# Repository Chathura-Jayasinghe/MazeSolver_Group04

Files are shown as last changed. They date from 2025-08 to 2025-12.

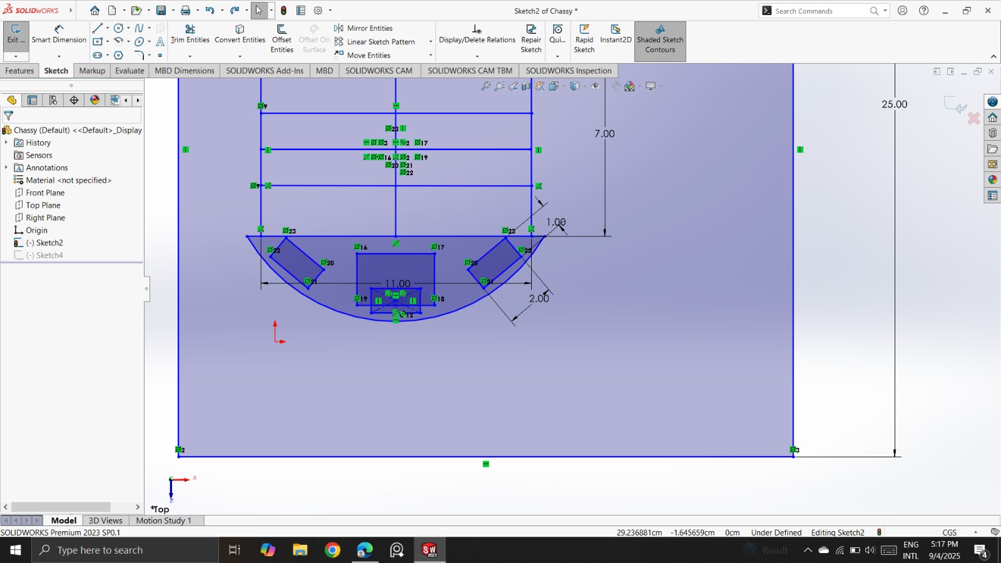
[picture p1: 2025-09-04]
images/WhatsApp Image 2025-09-04 at 17.18.16_0e4c124f.jpg

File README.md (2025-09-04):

# Maze-solving-robot

This project presents a **maze-solving robot** developed by **Group 4** as part of our coursework. The robot is designed to autonomously navigate through a maze by detecting paths, avoiding obstacles, and finding the optimal route to the destination.

The implementation focuses on:

* **Sensor integration** for line detection and obstacle avoidance.
* **Microcontroller programming** to execute decision-making algorithms.
* **Efficient pathfinding techniques** to minimize traversal time.
* **Robust mechanical design** for smooth and accurate movement.

Through this project, we aimed to enhance our knowledge of embedded systems, robotics, and algorithm design while working collaboratively as a team.

---

## Team Members – Group 4

| Member | Student ID | Name |
| --- | --- | --- |
| 1 | 210248E | J.M.C.N.B. Jayasinghe |
| 2 | 210367R | D.N. Manamperi |
| 3 | 210486F | M.R.M. Prabhashana |
| 4 | 210337C | G.N.K. Lakshitha |

---
<table>
  <tr>
    <td>
      Front View<br/>
      <p align="center"><b>Front View</b></p>
    </td>
    <td>
      Side View<br/>
      <p align="center"><b>Side View</b></p>
    </td>
    <td>
      Plan View<br/>
      <p align="center"><b>Plan View</b></p>
    </td>
  </tr>
</table>

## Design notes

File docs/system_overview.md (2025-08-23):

# System Overview – Maze Solving Robot

The Maze Solving Robot consists of three main subsystems: **sensing**, **decision making**, and **actuation**.

## High-Level Flow
1. **Sensors**  
   - IR sensors / ultrasonic sensors to detect walls.
   - Encoders to track movement (optional at this stage).

2. **Decision Making (Algorithm)**  
   - Apply a maze-solving algorithm (e.g., left-hand rule, DFS, BFS).
   - Store and update the map of the maze if needed.

3. **Actuation (Motors)**  
   - Motor drivers control wheels to move the robot.
   - Commands are based on algorithm decisions.

## Simple Block Diagram

```
[Sensors] → [Algorithm / Controller] → [Motors]
```

This simple flow will be refined as we add more detail.

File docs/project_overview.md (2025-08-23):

# Project Overview – Maze Solving Robot

This project aims to design and build a robot capable of autonomously solving a maze.  
The robot will use sensors to detect walls, apply a maze-solving algorithm, and navigate towards the exit.

## Possible Maze-Solving Algorithms

- **Left-hand rule**: Keep the left hand on the wall until the exit is found. Simple but not always optimal.
- **Right-hand rule**: Same as above, but with the right hand.
- **Depth-First Search (DFS)**: Explore as far as possible along one path before backtracking.
- **Breadth-First Search (BFS)**: Explore level by level, ensuring the shortest path is found.
- **Flood Fill**: Commonly used in micromouse competitions for efficient pathfinding.

## Goals for Initial Stage
- Set up basic hardware and PlatformIO environment.
- Represent maze structure in software.
- Test simple algorithms in simulation.

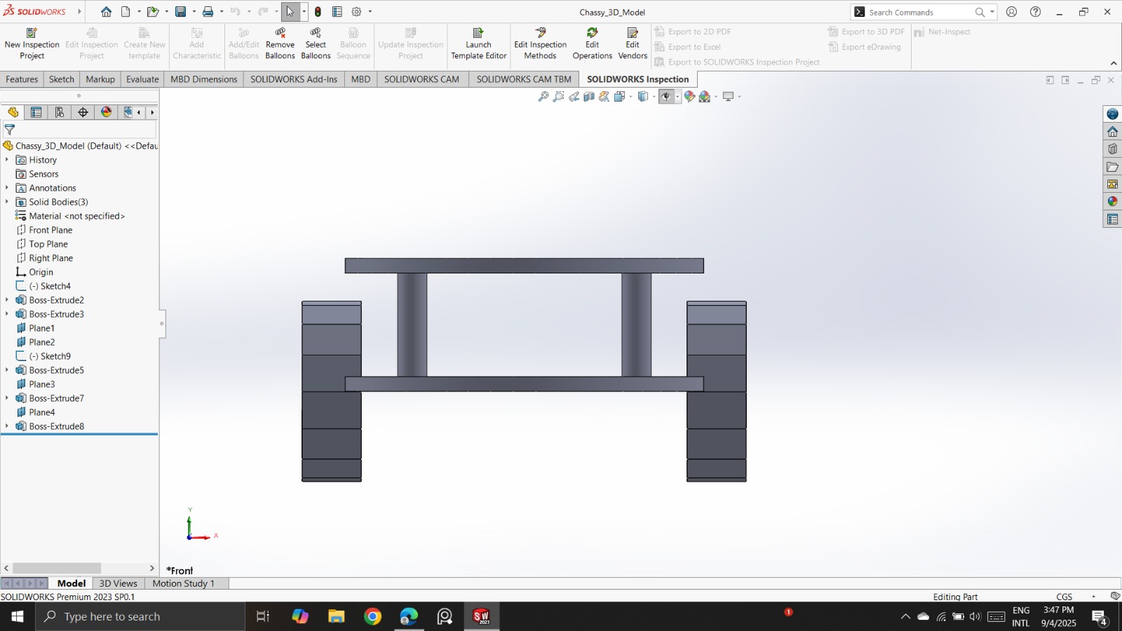
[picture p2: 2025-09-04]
images/front view.jpg

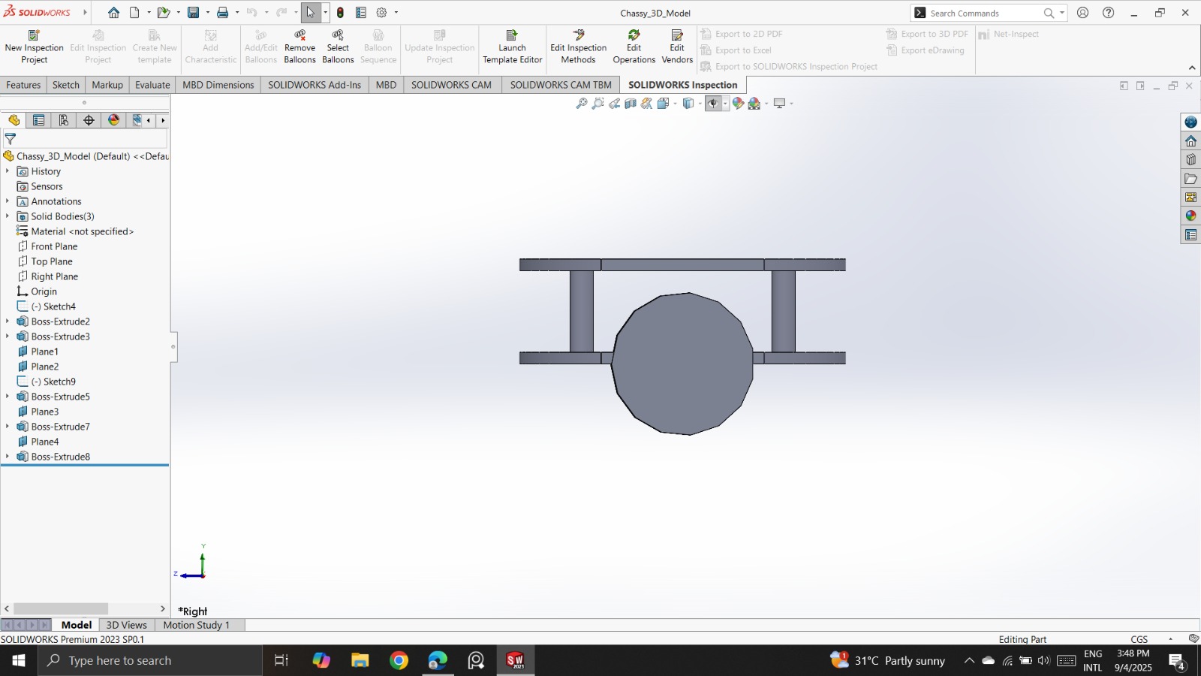
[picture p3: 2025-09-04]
images/side view.jpg

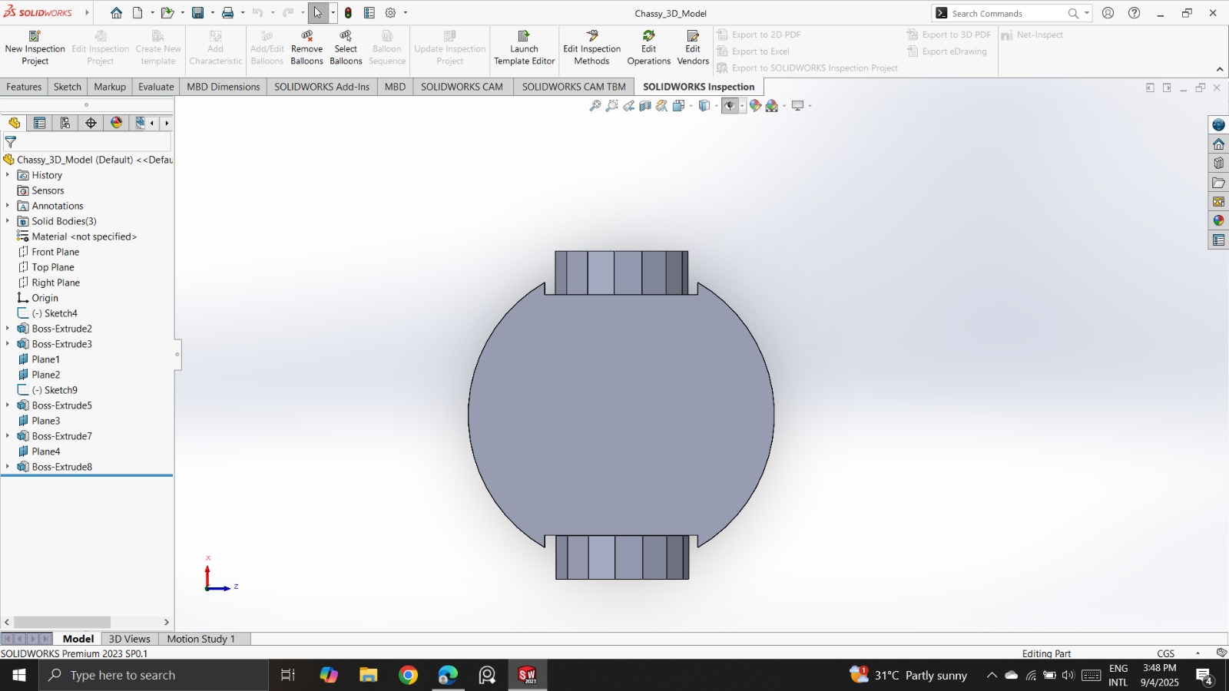
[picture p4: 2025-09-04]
images/plan view.jpg

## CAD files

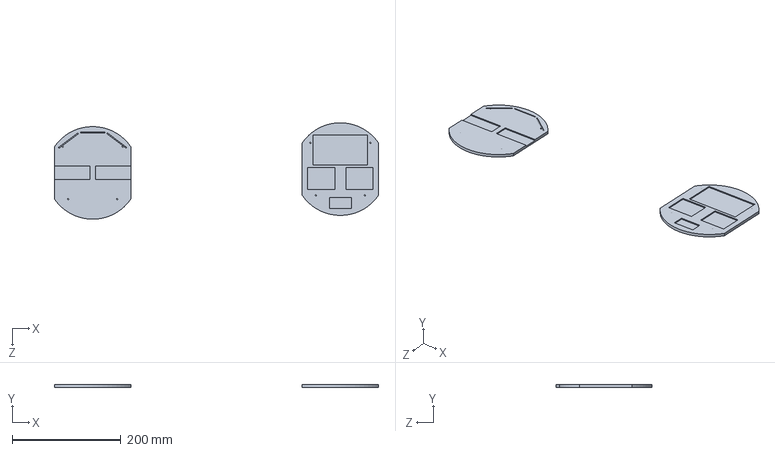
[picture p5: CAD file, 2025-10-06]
model design/Updated Dimensions_3D_Model_All.SLDPRT
594.5 x 5.00 x 176.9 mm

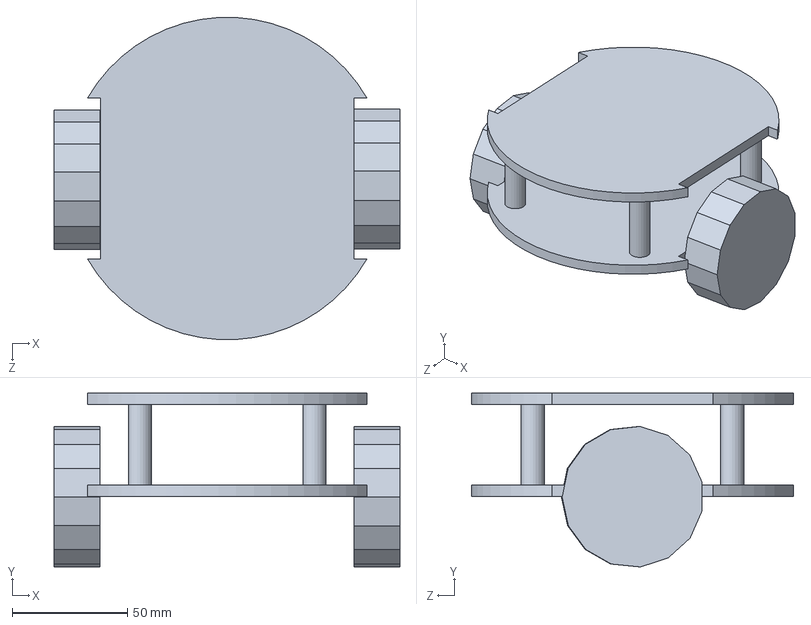
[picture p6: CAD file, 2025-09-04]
model design/Chassis_3D_Model.SLDPRT
150.2 x 75.5 x 139.8 mm

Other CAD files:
model design/Updated Dimensions.SLDPRT
model design/Chassis.SLDPRT

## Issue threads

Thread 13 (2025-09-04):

Draw 3D View of Maze Solving Robot

Chathura-Jayasinghe, 2025-09-04:
Description:
We need to design and draw a 3D view of the maze solving robot using SolidWorks. The model should represent the overall mechanical design, including the chassis, wheels, sensors, and motor placements. This will help us visualize the final build and make improvements before physical prototyping.

Closed 2025-09-04.

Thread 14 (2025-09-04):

Add Hardware Diagram and Wokwi Simulation Configuration

Chathura-Jayasinghe, 2025-09-04:
Description:
A new hardware diagram and Wokwi simulator configuration have been added to the project. These files define the hardware layout and set up the simulation environment for the Arduino Mega.

Details:

- Hardware Diagram (diagram.json)
- Defines hardware layout with Arduino Mega.
- Includes a red LED with specified wiring connections.
- Simulation Configuration (wokwi.toml)
- Configures the Wokwi simulator.
- Specifies firmware and ELF file locations for Arduino Mega.

Closed 2025-09-04.

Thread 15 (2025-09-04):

Update 3D View of Maze Solving Robot in Repository and Readme

Chathura-Jayasinghe, 2025-09-04:
Description:
The 3D design of the maze solving robot needs to be updated in the repository to reflect the latest design changes. This includes improvements in the chassis structure, motor placement, and sensor mounting positions. The updated model will help maintain consistency between the design and implementation phases.

Closed 2025-09-04.

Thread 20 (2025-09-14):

Add SolidWorks Design for Robot Chassisc

Chathura-Jayasinghe, 2025-09-14:
Description:
Create a detailed SolidWorks design of the robot chassis to serve as the foundation for the hardware build. The design should include proper dimensions, mounting points for motors, wheels, sensors, and space for the controller board and battery placement.

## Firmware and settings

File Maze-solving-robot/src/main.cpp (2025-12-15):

#include <Arduino.h>
#include "MotorPID.h"
#include "MazeSolver.h"
#include "LineFollower.h"

// --- Hardware Definitions ---
#define MOTOR1_IN1 8
#define MOTOR1_IN2 9
#define ENCODER1_A 3
#define ENCODER1_B 7

#define MOTOR2_IN1 5
#define MOTOR2_IN2 6
#define ENCODER2_A 2
#define ENCODER2_B 4

const int irPins[] = {IR1, IR2, IR3, IR4, IR5, IR6, IR7, IR8};
const int weights[] = {-3, -2, -1, 0, 0, 1, 2, 3};

MotorPID leftMotor(MOTOR1_IN1, MOTOR1_IN2, ENCODER1_A, ENCODER1_B, true);
MotorPID rightMotor(MOTOR2_IN1, MOTOR2_IN2, ENCODER2_A, ENCODER2_B, true);

MazeSolver mazeSolver(leftMotor, rightMotor);
LineFollower lineFollower(MOTOR1_IN1, MOTOR1_IN2, MOTOR2_IN1, MOTOR2_IN2, irPins, weights, 8);

bool allWhiteDetected()
{
    long sumStrength = 0;

    for (int i = 0; i < 8; i++) {
        int a = analogRead(irPins[i]);

        int strength = a - 800; // IR_THRESHOLD
        if (strength < 0) strength = 0;
        if (strength > 400) strength = 400; // MAX_STRENGTH

        sumStrength += strength;
    }

    // If all sensors detect white (low strength), return true
    return (sumStrength == 0);
}

void setup()
{
    Serial.begin(9600);

    leftMotor.begin();
    rightMotor.begin();
    mazeSolver.begin();
    lineFollower.setup();

    Serial.println();
    Serial.println("FLOOD FILL MAZE SOLVER");
    Serial.println("Starting in 2 seconds...");
    delay(2000);
}

// Mode: 0 = First Maze, 1 = Line Following, 2 = Second Maze
int currentMode = 0;

void loop()
{
    static unsigned long modeStartTime = 0;

    if (currentMode == 0)
    {
        // First maze solving mode
        if (allWhiteDetected())
        {
            float leftDist = mazeSolver.readSensor(US_LEFT_TRIG, US_LEFT_ECHO);
            float rightDist = mazeSolver.readSensor(US_RIGHT_TRIG, US_RIGHT_ECHO);

            if (leftDist < 15 && rightDist < 15)
            {
                Serial.println("All white detected with close walls! Switching to line following mode...");
                currentMode = 1;
                modeStartTime = millis(); // Record the time when switching to line-following mode
                leftMotor.setDirection(true);
                rightMotor.setDirection(true);
                leftMotor.setSpeed(80);
                rightMotor.setSpeed(80);
                delay(300);
                leftMotor.setSpeed(0);
                rightMotor.setSpeed(0);
            }
        }
        else
        {
            mazeSolver.runStep();
        }
    }
    else if (currentMode == 1)
    {
        lineFollower.followLine();

        // Line following mode
        if (millis() - modeStartTime > 10000) // Ensure at least 10 seconds in line-following mode
        {
            if (allWhiteDetected())
            {
                float leftDist = mazeSolver.readSensor(US_LEFT_TRIG, US_LEFT_ECHO);
                float rightDist = mazeSolver.readSensor(US_RIGHT_TRIG, US_RIGHT_ECHO);

                if (leftDist < 15 && rightDist < 15)
                {
                    Serial.println("All white detected with close walls! Switching to second maze solving mode...");
                    currentMode = 2;
                    leftMotor.setSpeed(80);
                    rightMotor.setSpeed(80);
                    delay(300);
                    leftMotor.setSpeed(0);
                    rightMotor.setSpeed(0);
                    mazeSolver.begin();
                }
            }
        }
    }
    else if (currentMode == 2)
    {
        // Second maze solving mode
        mazeSolver.runStep();
    }
}

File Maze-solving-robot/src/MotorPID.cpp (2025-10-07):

/*
  MotorPID.cpp - Motor control with encoder feedback
  Implementation file
*/

#include "MotorPID.h"

MotorPID* MotorPID::_instance1 = nullptr;
MotorPID* MotorPID::_instance2 = nullptr;

// Constructor
MotorPID::MotorPID(int in1Pin, int in2Pin, int encoderAPin, int encoderBPin, bool reversed) {
  _in1Pin = in1Pin;
  _in2Pin = in2Pin;
  _encoderAPin = encoderAPin;
  _encoderBPin = encoderBPin;
  _reversed = reversed;
  
  _speed = 0;
  _forward = true;
  _encoderCount = 0;
  
  // Assign instance number for ISR routing
  if (_instance1 == nullptr) {
    _instance1 = this;
    _instanceNum = 1;
  } else if (_instance2 == nullptr) {
    _instance2 = this;
    _instanceNum = 2;
  }
}

// Initialize motor and encoder
void MotorPID::begin() {
  pinMode(_in1Pin, OUTPUT);
  pinMode(_in2Pin, OUTPUT);
  
  pinMode(_encoderAPin, INPUT_PULLUP);
  pinMode(_encoderBPin, INPUT_PULLUP);
  
  if (_instanceNum == 1) {
    attachInterrupt(digitalPinToInterrupt(_encoderAPin), _encoderISR_A, CHANGE);
  } else if (_instanceNum == 2) {
    attachInterrupt(digitalPinToInterrupt(_encoderAPin), _encoderISR_B, CHANGE);
  }
  
  stop();
}

// Set motor direction
void MotorPID::setDirection(bool forward) {
  _forward = forward;
  _applyMotorControl();
}

// Set motor speed (0-255)
void MotorPID::setSpeed(int speed) {
  // Constrain speed to valid range
  _speed = constrain(speed, 0, 255);
  _applyMotorControl();
}

// Stop the motor
void MotorPID::stop() {
  _speed = 0;
  digitalWrite(_in1Pin, LOW);
  digitalWrite(_in2Pin, LOW);
}

// Update motor (call in loop)
void MotorPID::update() {
  // This function can be used for PID control in future
  // For now, it just maintains current speed/direction
  _applyMotorControl();
}

// Get encoder count
long MotorPID::getEncoderCount() {
  return _encoderCount;
}

// Reset encoder count
void MotorPID::resetEncoder() {
  noInterrupts();
  _encoderCount = 0;
  interrupts();
}

// Get current speed
int MotorPID::getSpeed() {
  return _speed;
}

// Get current direction
bool MotorPID::getDirection() {
  return _forward;
}

// Apply motor control based on speed and direction
void MotorPID::_applyMotorControl() {
  bool actualForward = _reversed ? !_forward : _forward;
  
  if (_speed == 0) {
    // Stop motor
    digitalWrite(_in1Pin, LOW);
    digitalWrite(_in2Pin, LOW);
  } else {
    if (actualForward) {
      // Forward direction
      analogWrite(_in1Pin, _speed);
      digitalWrite(_in2Pin, LOW);
    } else {
      // Backward direction
      digitalWrite(_in1Pin, LOW);
      analogWrite(_in2Pin, _speed);
    }
  }
}

// Handle encoder pulse
void MotorPID::_handleEncoder() {
  // Read both encoder pins
  int a = digitalRead(_encoderAPin);
  int b = digitalRead(_encoderBPin);
  
  // Determine direction and increment/decrement count
  if (a == b) {
    _encoderCount++;
  } else {
    _encoderCount--;
  }
}

// Static ISR for motor 1 (encoder A pin)
void MotorPID::_encoderISR_A() {
  if (_instance1 != nullptr) {
    _instance1->_handleEncoder();
  }
}

// Static ISR for motor 2 (encoder A pin)
void MotorPID::_encoderISR_B() {
  if (_instance2 != nullptr) {
    _instance2->_handleEncoder();
  }
}

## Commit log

2025-08-26 Update PlatformIO board from Uno to Mega
    Updates the platformio.ini file to change the target board from uno to megaatmega2560.
2025-09-04 Add initial Wokwi configuration and diagram for Arduino Mega project
2025-09-04 add dimensions for robot chassis #13
    SolidWorks Part files
    [Chassis.SLDPRT]
2025-09-04 design 3D model for robot #13
    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
    [Chassis_3D_Model.SLDPRT]
2025-10-06 Implement MotorPID class for dual motor control with PID functionality
2025-10-06 Refine MotorPID parameters and adjust REV_COUNT for improved motor control
2025-10-06 Merge pull request #21 from Chathura-Jayasinghe/Updated-3D-Model
    Updated 3D model - SOLIDWORKS
    [Updated Dimensions.SLDPRT, Updated Dimensions_3D_Model_All.SLDPRT]
2025-10-06 Add dual motor PID control and ultrasonic sensor functionality
2025-10-07 Refactor MotorPID class for improved structure and add wall-following logic in main loop
2025-10-18 define pin configurations
    For IR and Motors
2025-10-19 IR and motor testing
2025-10-21 Refactor wall-following logic and streamline motor control functions
2025-10-21 Refactor PID control parameters and improve wall-following speed calculations
2025-10-23 Fix typo in analogWrite function and add search_n_follow functionality
    [LineFollowing.cpp, search_n_follow.cpp]
2025-10-23 update maze-solving and line-following logic; integrate IR sensor handling and streamline control flow
2025-10-23 Update turn parameters and comment out initial motor setup in loop
2025-10-23 Refactor maze-solving logic; add wall-following function and adjust loop control flow
2025-12-15 Including shifting mode (#31)
    * Refactor MazeSolver to implement flood fill algorithm
    * Implement flood fill pathfinding and add IR target detection
    * Refactor MazeSolver and main loop for improved wall detection and debugging output
    * Comment out unused code for reset and follow modes in main loop and runStep function
    * Refactor MazeSolver and main to enhance structure and readability
    * function
    * ultrasonic
    * Comment out unused code in runStep and updateWalls functions; adjust COUNTS_PER_90 constant for improved performance
    * .
    * analog ir
    * Refactor LineFollower class to use motor pins directly; update setup and motor control methods for improved functionality
    * add
    * Refactor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
    [LineFollower.cpp, MazeSolver.cpp, MazeSolver.h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]
